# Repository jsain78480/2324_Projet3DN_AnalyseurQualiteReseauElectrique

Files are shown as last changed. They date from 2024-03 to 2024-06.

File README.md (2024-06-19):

# 2324_Projet3DN_AnalyseurQualiteReseauElectrique

# Consignes du projet
Il nous a été demandé de réaliser un projet de troisième année d'ingénieur en utilisant un STM32.
Le sujet de projet doit être validé avec le corps enseignant et doit être assez volumineux (Etaler sur 62h en autonomie).
Un GITHUB doit être créé et doit intégrer l'ensemble des éléments pour la création du projet (planning, cahier des charges, etc).
Il est préférable de réaliser un PCB 4 couches et de sous-traiter sa fabrication.
Les composants devront être soudé par les élèves. 

## Organisation du GITHUB

Nous avons ajouté différentes catégories dans notre GITHUB :
1) Hardware intègre tous les éléments permettant d'aboutir à la fabrication de nos PCB :       
   https://github.com/jsain78480/2324_Projet3DN_AnalyseurQualiteReseauElectrique/tree/main/Hardware 
2) Software intègre toute la programmation logiciel liée à STM32 Cube IDE :
   https://github.com/jsain78480/2324_Projet3DN_AnalyseurQualiteReseauElectrique/tree/main/Software
3) Projet intègre toute la méthodologie projet (Planning, cahier des charges) :
   https://github.com/jsain78480/2324_Projet3DN_AnalyseurQualiteReseauElectrique/tree/main/Projet

## Résumé du projet
Nous souhaitons réaliser un analyseur de réseau électrique dans le but d'évaluer la qualité d'un réseau electrique d'une entreprise.
Cette analyse permettra également à l'entreprise d'évaluer sa consommation électrique globale et de réévaluer l'offre qu'elle souscrit auprès de leur fournisseur.
Ce dispositif permet :
  - De récupérer la tension électrique du réseau monophasée ou triphasée
  - De mesurer le courant
  - De prélever la puissance du réseau
  - De prélever le spectre et en ressortir les harmoniques
  - D'afficher sur un écran les mesures instantannées
  - Gérer des alertes si le réseau comporte des problèmes

Le projet a commencé le 26 février et s'étend sur 62h. 
Vous pouvez trouver le planing du projet dans le répertoire projet.

## Le schéma du projet
Dessin2

## Le PCB d'acquisition



## Le PCB de traitement



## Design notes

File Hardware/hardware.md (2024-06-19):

# Carte d'acquisition permettant de récupérer le signal électrique

On a besoin d'une carte d'acquisition pour récupérer les tensions et les courants des 3 phases et du neutre de notre réseau triphasé. Pour se faire, nous allons faire un premier PCB qui sera appelé "Carte d'acquisition".
Nous avons listé ci-dessous l'ensemble des composants avec les caractéristiques techniques et les raisons du choix de ces derniers.

## Maquettage pour recherche des caractéristiques éléctriques











## Capteurs de tensions 
Référence : LEM LV 25-P 
Repères U1-U2-U3 
Rôle : Récupérer la tension de notre réseau électrique 
Composants choisis : Capteur de tension LEM LV 25-P
Raisons du choix : Le capteur LV25P est très précis et fiable, ce qui signifie qu'il mesure avec exactitude différentes tensions. Il est également facile à utiliser dans différents systèmes, ce qui le rend utile pour de nombreuses tâches. Ce dernier est donc très adapté avec notre projet d'analyseur de réseau électrique.

Caractèristiques techniques : 



Schéma technique : 



Dimensions du composants : 



Lien vers la datasheet : 

https://www.lem.com/sites/default/files/products_datasheets/lv_25-p.pdf 

Selon le datasheet "Voltage Transducer LV 25-P", on sait que :
 - Taux de conversion = 2500 : 1000
 - Courant Is = 25 mA
 - Donc conrant Iin = 10 mA

Tension d'entrée est 230 V au maximum et -230 V au minmum, donc on choisit Vin comme 500V, R1 = Vin  / Iin = 500/10mA = 50 Kohm, la puissance de l'entrée est Iin*Vin = 10*230 = 2.3 kW.

On a Vout = 3.3 V au maximum, donc Rm = Vout (au maximum) / Is = 3.3/25mA = 132 ohm.

En conclusion, le taux de la tension est : Vout/Vin = 3.3/230 = 0.0143.  

## OP1 à OP7 : AOP
Tension d'entrée : V1(Vout de U1)
Tension de sortie : V2
Resistance variable : pour calibrer V2 à 3,3V  

Tension d'entrée : Provient du traco avec +15v
Tension de sortie : 3,3v pour alimenter le STM, l'écran, les LEDS, etc

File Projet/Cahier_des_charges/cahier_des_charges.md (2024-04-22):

## Projet d'analyseur de réseau électrique 

Cadrage du besoin : 

Réaliser un analyseur de qualité de réseau électrique triphasée permettant :
- De mesurer la stabilité de la tension et du courant
- Mesures des tensions, des courants, des puissances actives, réactives et apparrentes. 
- Stabilité de la fréquence du réseau
- Mesure de la distorsion des harmoniques
- La vérification de l'équilibre des phases 

Pour informer l'utilisateur, le système doit :
- Informer l'utilisateur local avec un affichage en temps réel
- Informer un superviseur à distance avec un affichage temporel
- Pouvoir informer visuellement l'utilisateur d'une bonne ou mauvaise qualité de réseau

Enregistrement des données :
- Enregistrer en local les données mesurées
- Enregistrer à distance les données mesurées

Sécurité : 
- Le système doit garantir la sécurité de l'utilisateur

Matériels utilisés :
- Câble triphasé avec connecteur industriel 
- Coffret électrique
- Résistance de puissance pour débiter du courant
- Disjoncteur différentiel
- Pince ampéremétrique
- Carte PCB
- STM32

Spécifications techniques : 
- Tensions MAX = 230V 
- Courant MAX = 6A par phase
- Puissances Actives MAX = 
- Puissances Réactive MAX = 
- Puissances Apparentes MAX = 
- Montage souhaité = Etoile

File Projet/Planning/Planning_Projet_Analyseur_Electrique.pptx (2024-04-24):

## Planning projet analyseur électrique

Version 0 : Prévisionnel

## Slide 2

Activité

Choix du projet

Février

2024

T1

Mars

Avril

T2

Mai

Juin

Responsables

Validation du projet

Initialisation du GITHUB

26/02/2024

26/02/2024

28/02/2024

Jingwen/Hicham/Julien/Anas

Jingwen/Hicham/Julien/Anas

Mr Fiack et Mr Papazoglou

Rédaction du planning prévisionnel

Rédaction du cahier des charges

Réalisation du schéma de niveau 1 (haut niveau)

Jingwen/Hicham/Julien/Anas

Jingwen/Hicham/Julien/Anas

Jingwen/Hicham/Julien/Anas

Réalisation du schéma de niveau 3 (bas niveau)

Réalisation du schéma de niveau 2 (moyen niveau)

15/03/2024

22/03/2024

28/03/2024

Jingwen/Hicham/Julien/Anas

Jingwen/Hicham/Julien/Anas

KICAD de la carte d’acquisition

Choix des composants - Nomenclatures

KICAD de la carte de traitement

Jingwen/Hicham/Julien/Anas

Jingwen/Julien

Hicham/Anas

Débuter le software avec une carte de test (Nucléo)

Commande des composants (PCB avec GERBER)

Validation de la 1ère version des PCB

02/05/2024

17/05/2024

Jingwen/Julien

Mr Fiack et Mr Papazoglou

Mr Fiack et Mr Papazoglou

Commande des composants (hors PCB)

Réception des composants

Soudures des composants sur PCB

17/05/2024

31/05/2024

Jingwen/Hicham/Julien/Anas

Mr Fiack et Mr Papazoglou

Mr Fiack et Mr Papazoglou

Développement software phase 3 (Puissance)

Développement software phase 2 (Courants)

Développement software phase 1 (Tension)

31/05/2024

06/06/2024

07/06/2024

Jingwen/Hicham/Julien/Anas

Jingwen/Hicham/Julien/Anas

Développement software phase 4 (Harmoniques)

Développement software phase 5 (Ecran OLED)

07/06/2024

12/06/2024

Jingwen/Hicham/Julien/Anas

Jingwen/Hicham/Julien/Anas

Tests hardwares, tests softwares et validation du projet

Rédaction du planning définitif

Rédaction du retour d’expérience

Jingwen/Hicham/Julien/Anas

Jingwen/Hicham/Julien/Anas

Jingwen/Hicham/Julien/Anas

Présentation orale

Finalisation du GITHUB

14/06/2024

Jingwen/Hicham/Julien/Anas

Jingwen/Hicham/Julien/Anas

24/04/2024

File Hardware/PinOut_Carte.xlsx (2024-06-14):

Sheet: SUBD-Traitement-Acquisition
Projet Analyseur de réseau électrique
Signal | Carte d'acquisition | Cordon |  |  | Carte de traitement
Vph1 | P1-1 | P2-1 | Vph1 | P3-8 | P1-8
Vph2 | P1-2 | P2-2 | Vph2 | P3-7 | P1-7
Vph3 | P1-3 | P2-3 | Vph3 | P3-6 | P1-6
Vcurrent_ph1 | P1-9 | P2-9 | Vcurrent_ph1 | P3-15 | P1-15
Vcurrent_ph2 | P1-10 | P2-10 | Vcurrent_ph2 | P3-14 | P1-14
Vcurrent_ph3 | P1-11 | P2-11 | Vcurrent_ph3 | P3-13 | P1-13
Vcurrent_neutre | P1-4 | P2-4 | +15V | P3-5 | P1-5
+15V | P1-15 | P2-15 | Vcurrent_neutre | P3-9 | P1-9
GND | P1-8 | P2-8 | GND | P3-1 | P1-1

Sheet: SUBD-STM32
Projet Analyseur de réseau électrique
Signal | STM32G4 | Carte de traitement
Vph1 |  | P1-8
Vph2 |  | P1-7
Vph3 |  | P1-6
Vcurrent_ph1 |  | P1-15
Vcurrent_ph2 |  | P1-14
Vcurrent_ph3 |  | P1-13
Vcurrent_neutre |  | P1-5
+15V |  | P1-9
GND |  | P1-1

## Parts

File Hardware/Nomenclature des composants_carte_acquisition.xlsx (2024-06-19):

Projet Analyseur de Réseau Electrique
Nomenclature des composants
Designation | Repère CI | Références constructeur | Référence fournisseur | Quantité | Prix | Fournisseur | Prix total | Coût Carte d'acquisition | Coût carte de traitement | Coût total
 |  |  |  |  |  |  |  | 373.26 |  | 373.26
Capteur de tension | U1, U2, U3 | LV 25-P | 1617416 | 3 | 77.53 | FARNELL | 232.59
Fiches bananes 4mm femelle Rouge | J1 | SWEB 8094 AU / RT (https://fr.farnell.com/schutzinger/sweb-8094-au-rt/fiche-banane-femelle-24a-rouge/dp/3224813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) | 3224813 | 2 | 5.81 | FARNELL | 11.62
Fiches bananes 4mm femelle Jaune | J2 | SWEB 8094 AU / GE (https://fr.farnell.com/schutzinger/sweb-8094-au-ge/fiche-banane-femelle-24a-jaune/dp/3224811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) | 3224811 | 1 | 5.65 | FARNELL | 5.65
Fiches bananes 4mm femelle Bleu | J3 | SWEB 8094 AU / BL (https://fr.farnell.com/schutzinger/sweb-8094-au-bl/conn-banane-femelle-24a-bleu/dp/3224810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) | 3224810 | 1 | 5.43 | FARNELL | 5.43
Fiches bananes 4mm femelle Noir | J4 | SWEB 8094 AU / SW (https://fr.farnell.com/schutzinger/sweb-8094-au-sw/conn-banane-femelle-24a-noir/dp/3224814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) | 3224814 | 2 | 5.76 | FARNELL | 11.52
Alimentation Traco Power +/- 15V | AL1 | TMP 15215 (https://www.mouser.fr/ProductDetail/TRACO-Power/TMP-30215?qs=ckJk83FOD0XyGILCEMzHzw%3D%3D) | 495-TMP15215 | 1 | 40.39 | MOUSER | 40.39
 |  |  |  |  |  |  | 0
Connecteur SubD 15 pts Mâle | P1 | 618015231421 | 710-618015231421 | 1 | 0 | ENSEA | 0
Connecteur SubD 15 pts Femelle | P2,P3 | 61801524923 | 710-61801524923 | 2 | 2.04 | MOUSER | 4.08
Régulateur 3,3V | REG1 | LM2937ESX-3.3/NOPB | 3122059 | 1 | 2.41 | FARNELL | 2.41
Amplificateur | OP1 à OP7 | OP275GSZ (https://fr.farnell.com/analog-devices/op275gsz/ampli-op-9mhz-40-a-85-c-nsoic/dp/4021486?st=op275) | 4021486 | 7 | 4.13 | FARNELL | 28.91
Connecteur BNC | J1 à J4 |  | 217-7787 | 4 | 6.16 | RS | 24.64
Porte fusible | PF1 | MC000830 | 2461161 | 1 | 0.702 | FARNELL | 0.702
Fusible (250mA 5 x 20mm Type F 250V c.a) | F1 |  | 563-469 | 1 | 0.315 | RS | 0.315
LED verte |  |  |  | 2 | 0 | ENSEA | 0
LED Orange |  |  |  | 1 | 0 | ENSEA | 0
 |  |  |  |  |  |  | 0
Résistances 25kΩ/6W | R21, R26, R31, R36 | 356024KFT | 3231229 | 4 | 1.25 | Farnell | 5
Résistances CMS 100Ω R_0603_1608Metric_Pad0.98x0.95mm | R23, R24, R28, R29, R33, R34 |  |  |  |  |  | 0
Résistances CMS 1kΩ R_0603_1608Metric_Pad0.98x0.95mm | R3, R4, R5, R7, R8, R9, R11, R12, R13, R15, R16, R17, R19, R20, R22, R25, R27, R30, R32 |  |  | 19 | 0 | ENSEA | 0
Résistances CMS 4,5kΩ R_0603_1608Metric_Pad0.98x0.95mm | R6, R10, R14, R18 |  |  | 4 | 0 | ENSEA | 0
Résistances CMS 7,5kΩ R_0603_1608Metric_Pad0.98x0.95mm | R1, R2 |  |  | 2 | 0 | ENSEA | 0
 |  |  |  |  |  |  | 0
Condensateur CMS 0,1uF C_0603_1608Metric_Pad1.08x0.95mm | C1, C3 à C14 |  |  | 13 | 0 | ENSEA | 0
Condensateur CMS 10uF C_0603_1608Metric_Pad1.08x0.95mm | C2 |  |  | 1 | 0 | ENSEA | 0

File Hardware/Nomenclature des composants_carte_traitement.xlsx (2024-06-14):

Projet Analyseur de Réseau Electrique
Nomenclature des composants
Designation | Repère CI | Références constructeur | Référence fournisseur | Quantité | Prix | Fournisseur | Prix total | Coût carte de traitement | Coût total
 |  |  |  |  |  |  |  | 0.00 | 0.00
Microprocesseur | U2 | STM32G474RET6 | 3132418 | 1 | 0 | ENSEA | 0
MagI3C Power Module | WE1 | 173950x78 | 173950x78 | 1 | 0 | ENSEA | 0
OLED | OLED1 |  |  | 1 | 0 | ENSEA | 0
LED verte | D2 |  |  | 1 | 0 | ENSEA | 0
LED Orange | D1 |  |  | 1 | 0 | ENSEA | 0
Tact Switch | S1,S2,S3,S4 |  |  | 4 | 0 | ENSEA | 0
Connecteur SubD 15 pts Femelle | J2 | 618015231321 | 710-618015231321 | 1 | 0 | ENSEA | 0
Connecteur 02x07 Odd_Even | J1 |  |  | 1 | 0 | ENSEA | 0
Condensateur CMD 4,7uF C_0603_1608Metric_Pad1.08x0.95mm | C1 |  |  | 1 | 0 | ENSEA | 0
Condensateur CMD 100nF C_0603_1608Metric_Pad1.08x0.95mm | C2,C3,C7 |  |  | 3 | 0 | ENSEA | 0
Condensateur CMD 10nF C_0603_1608Metric_Pad1.08x0.95mm | C4,C8 à C11 |  |  | 5 | 0 | ENSEA | 0
Condensateur CMD 1uF C_0603_1608Metric_Pad1.08x0.95mm | C5,C6 |  |  | 2 | 0 | ENSEA | 0
Inductance CMD 39nH L_0603_1608Metric_Pad1.05x0.95mm | L1 |  |  | 1 | 0 | ENSEA | 0
Résistances CMS 180Ω R_0603_1608Metric_Pad0.98x0.95mm | R1 |  |  | 1 | 0 | ENSEA | 0
Résistances CMS 240Ω R_0603_1608Metric_Pad0.98x0.95mm | R2 |  |  | 1 | 0 | ENSEA | 0
Résistances CMS 10kΩ R_0603_1608Metric_Pad0.98x0.95mm | R3 à R10 |  |  | 8 | 0 | ENSEA | 0

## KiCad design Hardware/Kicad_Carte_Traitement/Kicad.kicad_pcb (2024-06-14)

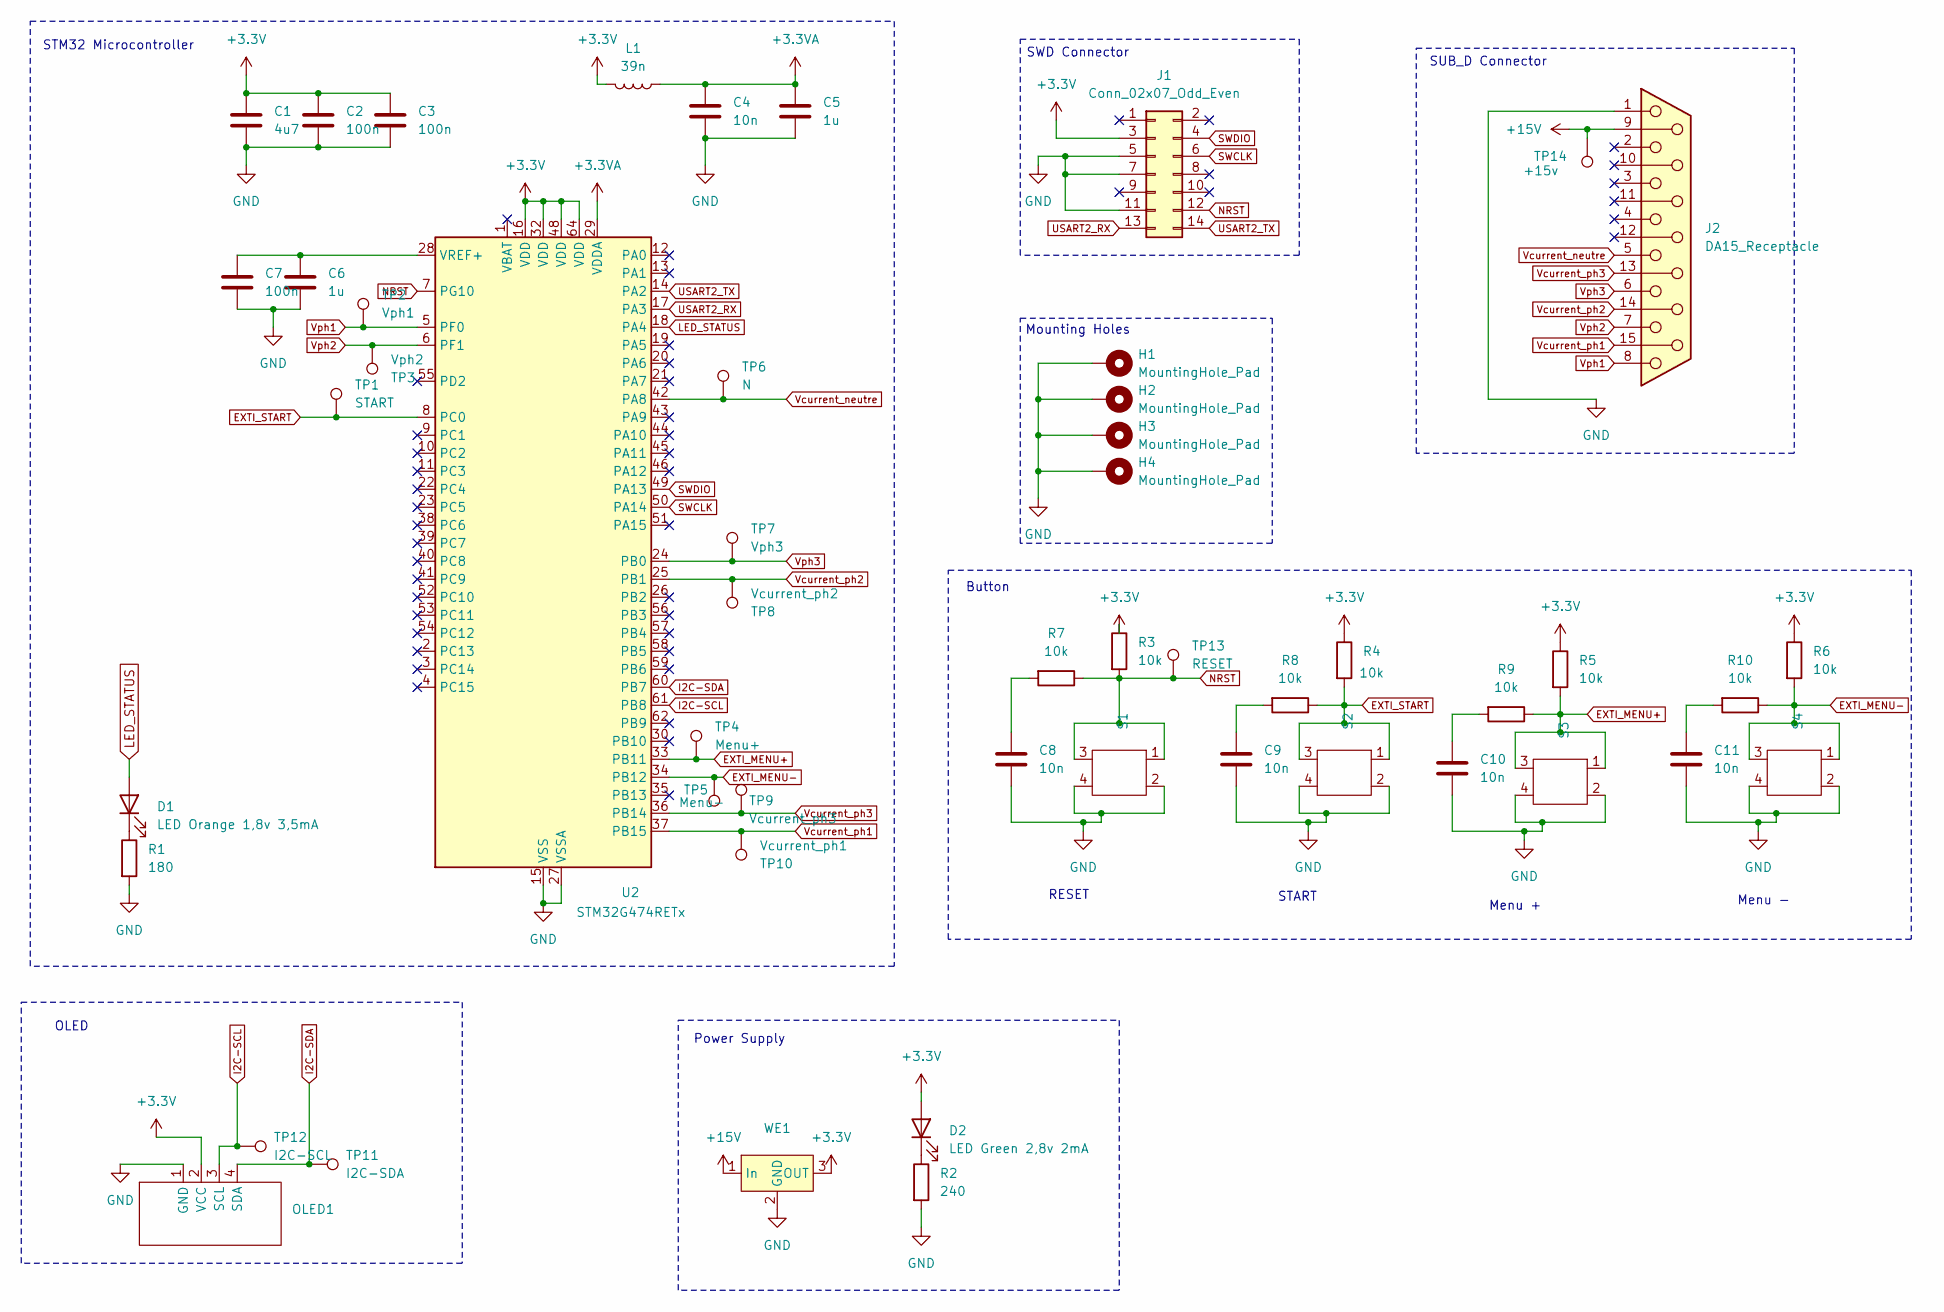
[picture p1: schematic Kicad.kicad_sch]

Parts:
C1: 4u7; C_0603_1608Metric_Pad1.08x0.95mm_HandSolder
C2, C3, C7: 100n; C_0603_1608Metric_Pad1.08x0.95mm_HandSolder
C4, C8, C9, C10, C11: 10n; C_0603_1608Metric_Pad1.08x0.95mm_HandSolder
C5, C6: 1u; C_0603_1608Metric_Pad1.08x0.95mm_HandSolder
D1: LED Orange 1,8v 3,5mA; LED_0603_1608Metric_Pad1.05x0.95mm_HandSolder
D2: LED Green 2,8v 2mA; LED_0603_1608Metric_Pad1.05x0.95mm_HandSolder
H1, H2, H3, H4: MountingHole_Pad; MountingHole_3.2mm_M3_Pad
J1: Conn_02x07_Odd_Even; IDC-Header_2x07_P2.54mm_Vertical_SMD
J2: DA15_Receptacle; 618015231321
L1: 39n; L_0603_1608Metric_Pad1.05x0.95mm_HandSolder
OLED1: OLED
R1: 180; R_0603_1608Metric_Pad0.98x0.95mm_HandSolder
R2: 240; R_0603_1608Metric_Pad0.98x0.95mm_HandSolder
R3, R4, R5, R6, R7, R8, R9, R10: 10k; R_0603_1608Metric_Pad0.98x0.95mm_HandSolder
S1, S2, S3, S4: Tact_switch
TP1: START; Pin_D1.2mm_L10.2mm_W2.9mm_FlatFork
TP2: Vph1; Pin_D1.2mm_L10.2mm_W2.9mm_FlatFork
TP3: Vph2; Pin_D1.2mm_L10.2mm_W2.9mm_FlatFork
TP4: Menu+; Pin_D1.2mm_L10.2mm_W2.9mm_FlatFork
TP5: Menu-; Pin_D1.2mm_L10.2mm_W2.9mm_FlatFork
TP6: N; Pin_D1.2mm_L10.2mm_W2.9mm_FlatFork
TP7: Vph3; Pin_D1.2mm_L10.2mm_W2.9mm_FlatFork
TP8: Vcurrent_ph2; Pin_D1.2mm_L10.2mm_W2.9mm_FlatFork
TP9: Vcurrent_ph3; Pin_D1.2mm_L10.2mm_W2.9mm_FlatFork
TP10: Vcurrent_ph1; Pin_D1.2mm_L10.2mm_W2.9mm_FlatFork
TP11: I2C-SDA; Pin_D1.2mm_L10.2mm_W2.9mm_FlatFork
TP12: I2C-SCL; Pin_D1.2mm_L10.2mm_W2.9mm_FlatFork
TP13: RESET; Pin_D1.2mm_L10.2mm_W2.9mm_FlatFork
TP14: +15v; Pin_D1.2mm_L10.2mm_W2.9mm_FlatFork
U2: STM32G474RETx; LQFP-64_10x10mm_P0.5mm
WE1: test

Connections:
+3.3V: C1.1, C2.1, C3.1, D2.2 (A), J1.3, L1.2, OLED1.2 (VCC), R3.1, R4.1, R5.1, R6.1, U2.16 (VDD), U2.32 (VDD), U2.48 (VDD), U2.64 (VDD), WE1.3 (OUT)
+3.3VA: C4.1, C5.1, L1.1, U2.29 (VDDA)
+15V: J2.9, TP14.1, WE1.1 (In)
EXTI_MENU+: R5.2, R9.1, S3.1, S3.3, TP4.1, U2.33 (PB11)
EXTI_MENU-: R6.2, R10.1, S4.1, S4.3, TP5.1, U2.34 (PB12)
EXTI_START: R4.2, R8.1, S2.1, S2.3, TP1.1, U2.8 (PC0)
GND: C1.2, C2.2, C3.2, C4.2, C5.2, C6.2, C7.2, C8.2, C9.2, C10.2, C11.2, H1.1, H2.1, H3.1, H4.1, J1.5, J1.7, J1.11, J2.1, OLED1.1 (GND), R1.2, R2.2, S1.2, S1.4, S2.2, S2.4, S3.2, S3.4, S4.2, S4.4, U2.15 (VSS), U2.27 (VSSA), U2.31 (VSS), U2.47 (VSS), U2.63 (VSS), WE1.2 (GND)
I2C-SCL: OLED1.3 (SCL), TP12.1, U2.61 (PB8)
I2C-SDA: OLED1.4 (SDA), TP11.1, U2.60 (PB7)
LED_STATUS: D1.2 (A), U2.18 (PA4)
NRST: J1.12, R3.2, R7.1, S1.1, S1.3, TP13.1, U2.7 (PG10)
unnamed: C8.1, R7.2
unnamed: C9.1, R8.2
unnamed: C10.1, R9.2
unnamed: C11.1, R10.2
unnamed: D1.1 (K), R1.1
unnamed: D2.1 (K), R2.1
unnamed: C6.1, C7.1, U2.28 (VREF+)
SWCLK: J1.6, U2.50 (PA14)
SWDIO: J1.4, U2.49 (PA13)
USART2_RX: J1.13, U2.17 (PA3)
USART2_TX: J1.14, U2.14 (PA2)
Vcurrent_neutre: J2.5, TP6.1, U2.42 (PA8)
Vcurrent_ph1: J2.15, TP10.1, U2.37 (PB15)
Vcurrent_ph2: J2.14, TP8.1, U2.25 (PB1)
Vcurrent_ph3: J2.13, TP9.1, U2.36 (PB14)
Vph1: J2.8, TP2.1, U2.5 (PF0)
Vph2: J2.7, TP3.1, U2.6 (PF1)
Vph3: J2.6, TP7.1, U2.24 (PB0)

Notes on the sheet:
STM32 Microcontroller
Power Supply
SUB_D Connector
Menu -
Button
SWD Connector
OLED
START
RESET
Menu +
Mounting Holes

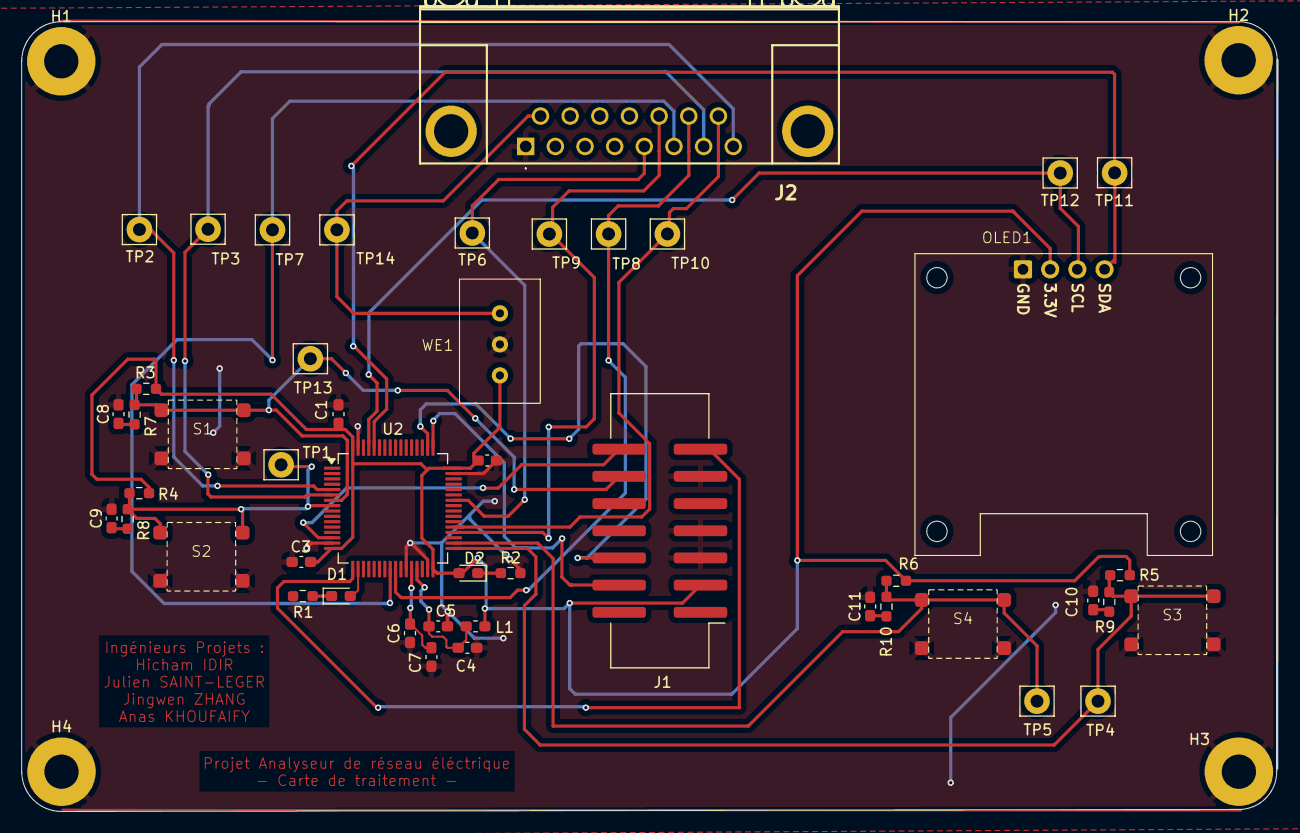
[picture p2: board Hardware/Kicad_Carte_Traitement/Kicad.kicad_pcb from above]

Board: 2 copper layers, 117.3 x 73.8 mm, 51 parts (0 on the bottom side), 29 nets.

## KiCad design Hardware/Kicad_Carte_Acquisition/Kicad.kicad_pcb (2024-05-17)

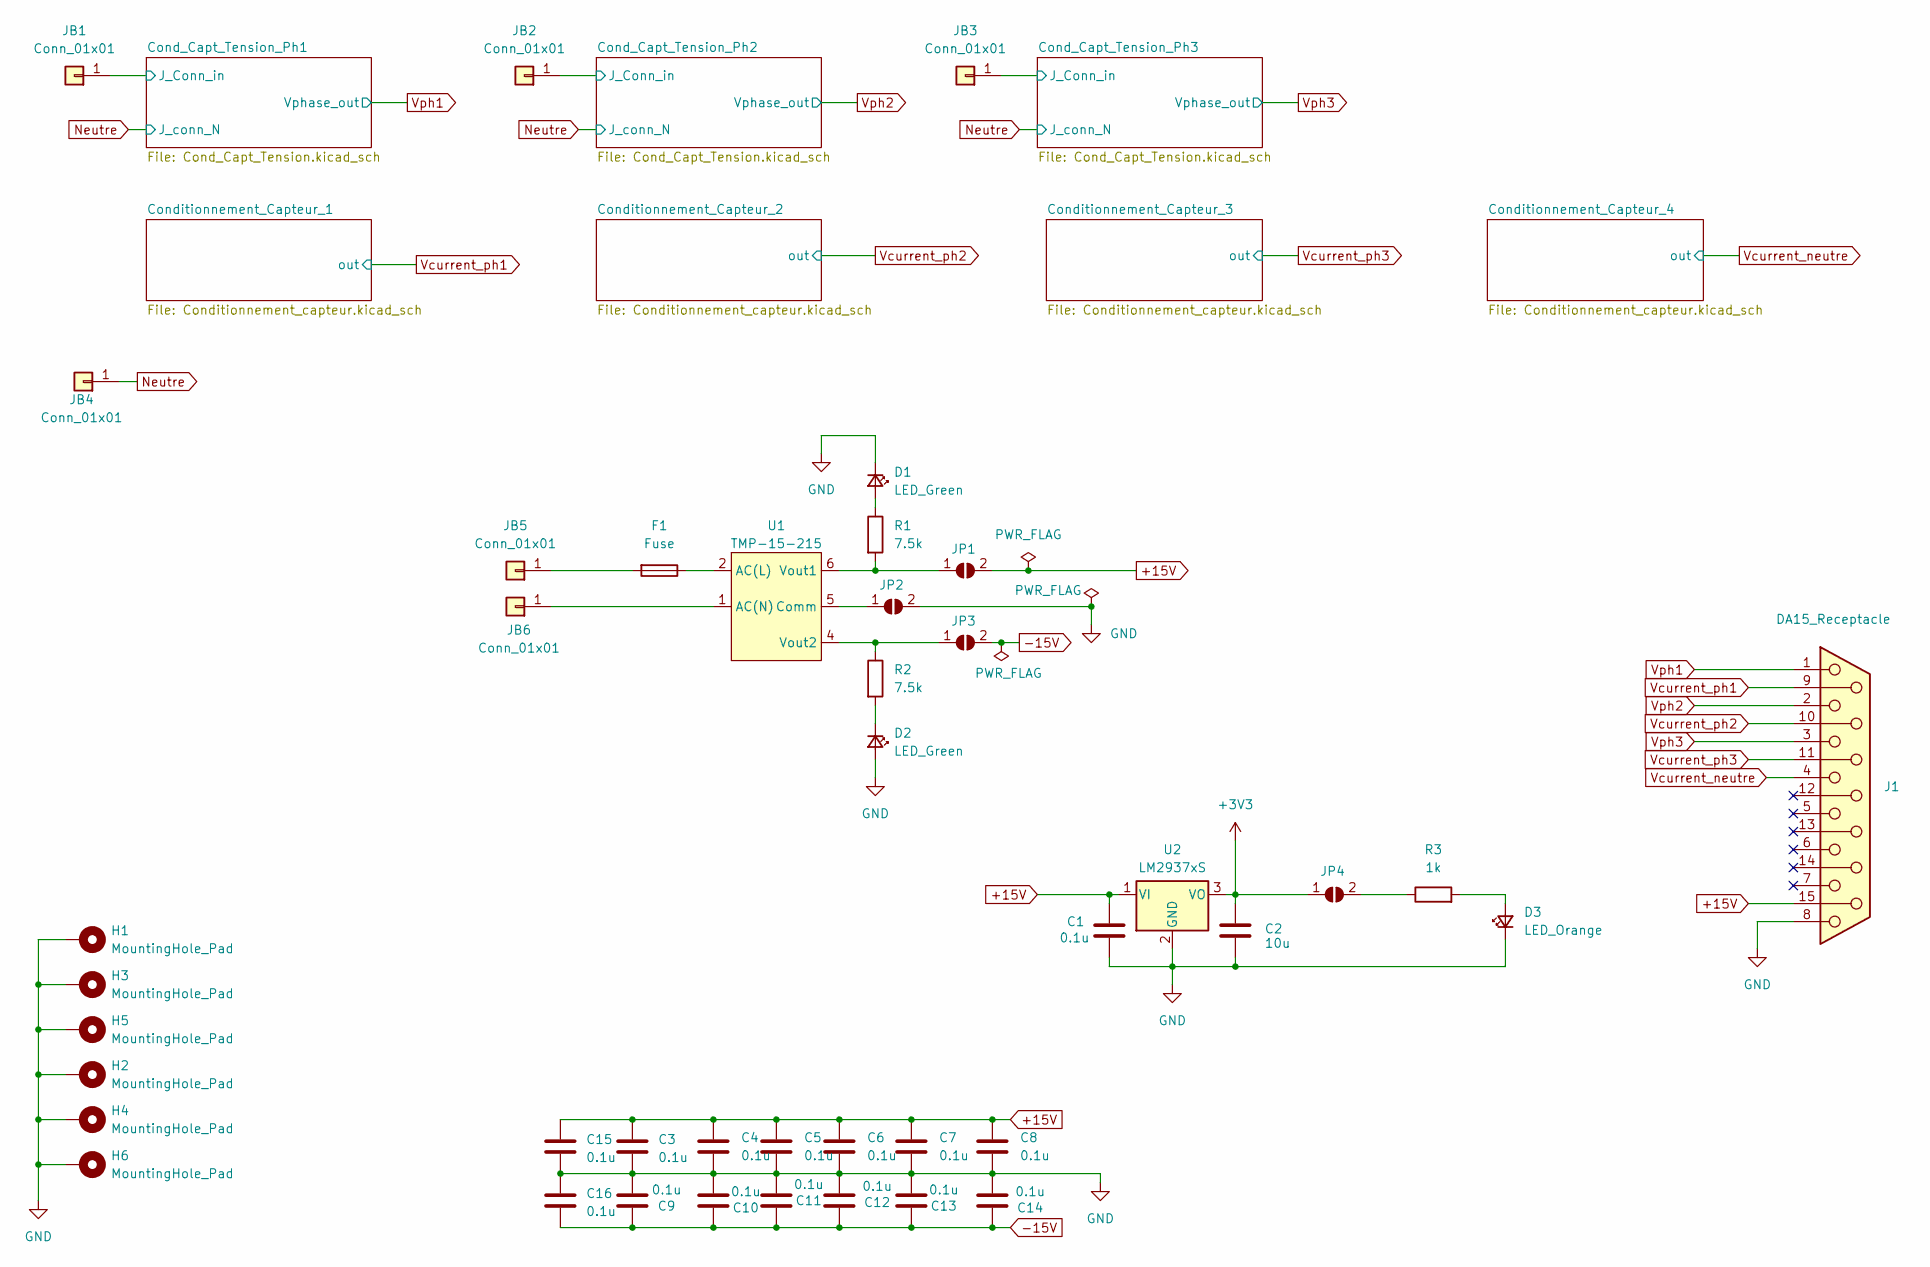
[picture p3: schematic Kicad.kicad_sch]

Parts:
C1, C3, C4, C5, C6, C7, C8, C9, C10, C11, C12, C13, C14, C15, C16: 0.1u; C_0603_1608Metric_Pad1.08x0.95mm_HandSolder
C2: 10u; C_0603_1608Metric_Pad1.08x0.95mm_HandSolder
D1, D2: LED_Green; LED_0603_1608Metric_Pad1.05x0.95mm_HandSolder
D3: LED_Orange; LED_0603_1608Metric_Pad1.05x0.95mm_HandSolder
F1: Fuse; Porte_Fusible_PC1E
H1, H2, H3, H4, H5, H6: MountingHole_Pad; MountingHole_3.2mm_M3_Pad
J1: DA15_Receptacle; 618015231321
JB1, JB2, JB3, JB4, JB5, JB6: Conn_01x01; Banana_Cliff_FCR7350B_S16N-PC_Horizontal
JP1, JP2, JP3, JP4: SolderJumper_2_Open; SolderJumper-2_P1.3mm_Open_TrianglePad1.0x1.5mm
R1, R2: 7.5k; R_0603_1608Metric_Pad0.98x0.95mm_HandSolder
R3: 1k; R_0603_1608Metric_Pad0.98x0.95mm_HandSolder
U1: TMP-15-215; TMP-15-215E
U2: LM2937xS; TO-263-3_TabPin2

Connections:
+3V3: C2.1, JP4.1 (A), U2.3 (VO); also elsewhere on the board
+15V: C1.1, C3.1, C4.1, C5.1, C6.1, C7.1, C8.1, C15.1, J1.15, JP1.2 (B), U2.1 (VI); also elsewhere on the board
-15V: C9.1, C10.1, C11.1, C12.1, C13.1, C14.1, C16.2, JP3.2 (B); also elsewhere on the board
/Cond_Capt_Tension_Ph1/J_Conn_in: JB1.1; also elsewhere on the board
/Cond_Capt_Tension_Ph2/J_Conn_in: JB2.1; also elsewhere on the board
/Cond_Capt_Tension_Ph3/J_Conn_in: JB3.1; also elsewhere on the board
GND: C1.2, C2.2, C3.2, C4.2, C5.2, C6.2, C7.2, C8.2, C9.2, C10.2, C11.2, C12.2, C13.2, C14.2, C15.2, C16.1, D1.1 (K), D2.2 (A), D3.1 (K), H1.1, H2.1, H3.1, H4.1, H5.1, H6.1, J1.8, JP2.2 (B), U2.2 (GND); also elsewhere on the board
unnamed: D1.2 (A), R1.1
unnamed: D2.1 (K), R2.2
unnamed: D3.2 (A), R3.2
unnamed: F1.2, JB5.1
unnamed: JB6.1, U1.1 (AC(N))
unnamed: JP1.1 (A), R1.2, U1.6 (Vout1)
unnamed: JP2.1 (A), U1.5 (Comm)
unnamed: JP3.1 (A), R2.1, U1.4 (Vout2)
unnamed: JP4.2 (B), R3.1
unnamed: F1.1, U1.2 (AC(L))
Neutre: JB4.1; also elsewhere on the board
Vcurrent_neutre: J1.4; also elsewhere on the board
Vcurrent_ph1: J1.9; also elsewhere on the board
Vcurrent_ph2: J1.10; also elsewhere on the board
Vcurrent_ph3: J1.11 (P111); also elsewhere on the board
Vph1: J1.1; also elsewhere on the board
Vph2: J1.2; also elsewhere on the board
Vph3: J1.3; also elsewhere on the board

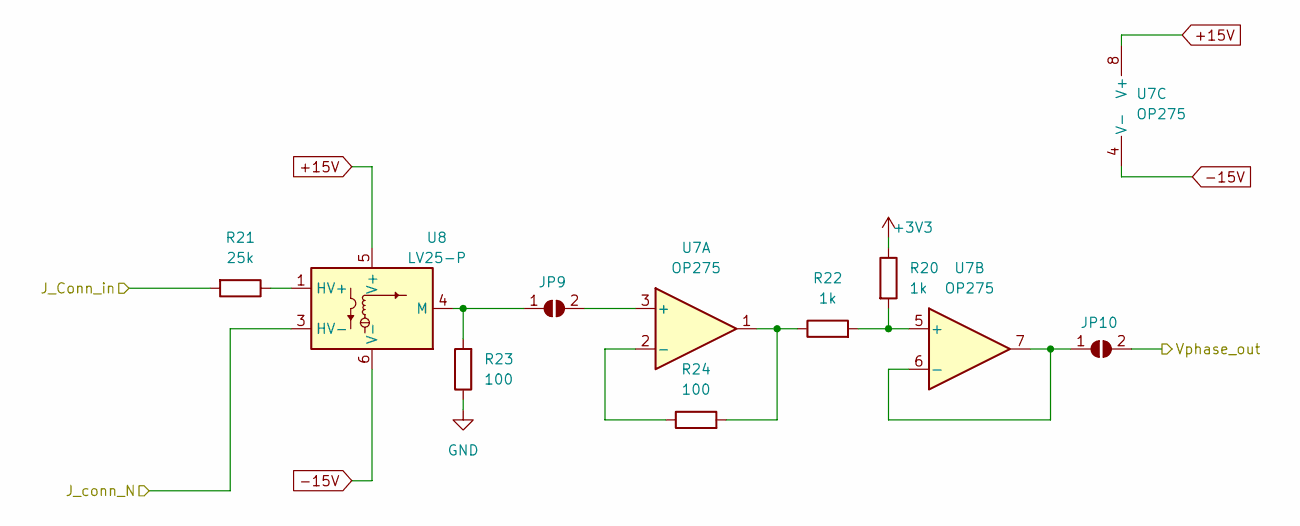
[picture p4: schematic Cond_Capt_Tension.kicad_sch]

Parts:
JP9, JP10: SolderJumper_2_Open; SolderJumper-2_P1.3mm_Open_TrianglePad1.0x1.5mm
R20, R22: 1k; R_0603_1608Metric_Pad0.98x0.95mm_HandSolder
R21: 25k; R_4527_M11470E
R23, R24: 100; R_0603_1608Metric_Pad0.98x0.95mm_HandSolder
U7: OP275; SOIC-8_3.9x4.9mm_P1.27mm
U8: LV25-P; LEM_LV25-P

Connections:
+3V3: R20.1; also elsewhere on the board
+15V: U7.8 (V+), U8.5 (V+); also elsewhere on the board
-15V: U7.4 (V-), U8.6 (V-); also elsewhere on the board
/Cond_Capt_Tension_Ph1/J_Conn_in: R21.2; also elsewhere on the board
GND: R23.1; also elsewhere on the board
unnamed: JP9.1 (A), R23.2, U8.4 (M)
unnamed: JP9.2 (B), U7.3 (+)
unnamed: JP10.1 (A), U7.6 (-), U7.7
unnamed: R22.1, R24.2, U7.1
unnamed: R24.1, U7.2 (-)
unnamed: R20.2, R22.2, U7.5 (+)
unnamed: R21.1, U8.1 (HV+)
Neutre: U8.3 (HV-); also elsewhere on the board
Vph1: JP10.2 (B); also elsewhere on the board

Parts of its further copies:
JP11, JP12, JP13, JP14: SolderJumper_2_Open; SolderJumper-2_P1.3mm_Open_TrianglePad1.0x1.5mm
R25, R27, R30, R32: 1k; R_0603_1608Metric_Pad0.98x0.95mm_HandSolder
R26, R31: 25k; R_4527_M11470E
R28, R29, R33, R34: 100; R_0603_1608Metric_Pad0.98x0.95mm_HandSolder
U9, U11: OP275; SOIC-8_3.9x4.9mm_P1.27mm
U10, U12: LV25-P; LEM_LV25-P

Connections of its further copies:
+3V3: R25.1, R30.1; also elsewhere on the board
+15V: U9.8 (V+), U10.5 (V+), U11.8 (V+), U12.5 (V+); also elsewhere on the board
-15V: U9.4 (V-), U10.6 (V-), U11.4 (V-), U12.6 (V-); also elsewhere on the board
/Cond_Capt_Tension_Ph2/J_Conn_in: R26.2; also elsewhere on the board
/Cond_Capt_Tension_Ph3/J_Conn_in: R31.2; also elsewhere on the board
GND: R28.1, R33.1; also elsewhere on the board
unnamed: JP11.1 (A), R28.2, U10.4 (M)
unnamed: JP11.2 (B), U9.3 (+)
unnamed: JP12.1 (A), U9.6 (-), U9.7
unnamed: JP13.1 (A), R33.2, U12.4 (M)
unnamed: JP13.2 (B), U11.3 (+)
unnamed: JP14.1 (A), U11.6 (-), U11.7
unnamed: R27.1, R29.2, U9.1
unnamed: R32.1, R34.2, U11.1
unnamed: R29.1, U9.2 (-)
unnamed: R25.2, R27.2, U9.5 (+)
unnamed: R26.1, U10.1 (HV+)
unnamed: R34.1, U11.2 (-)
unnamed: R30.2, R32.2, U11.5 (+)
unnamed: R31.1, U12.1 (HV+)
Neutre: U10.3 (HV-), U12.3 (HV-); also elsewhere on the board
Vph2: JP12.2 (B); also elsewhere on the board
Vph3: JP14.2 (B); also elsewhere on the board

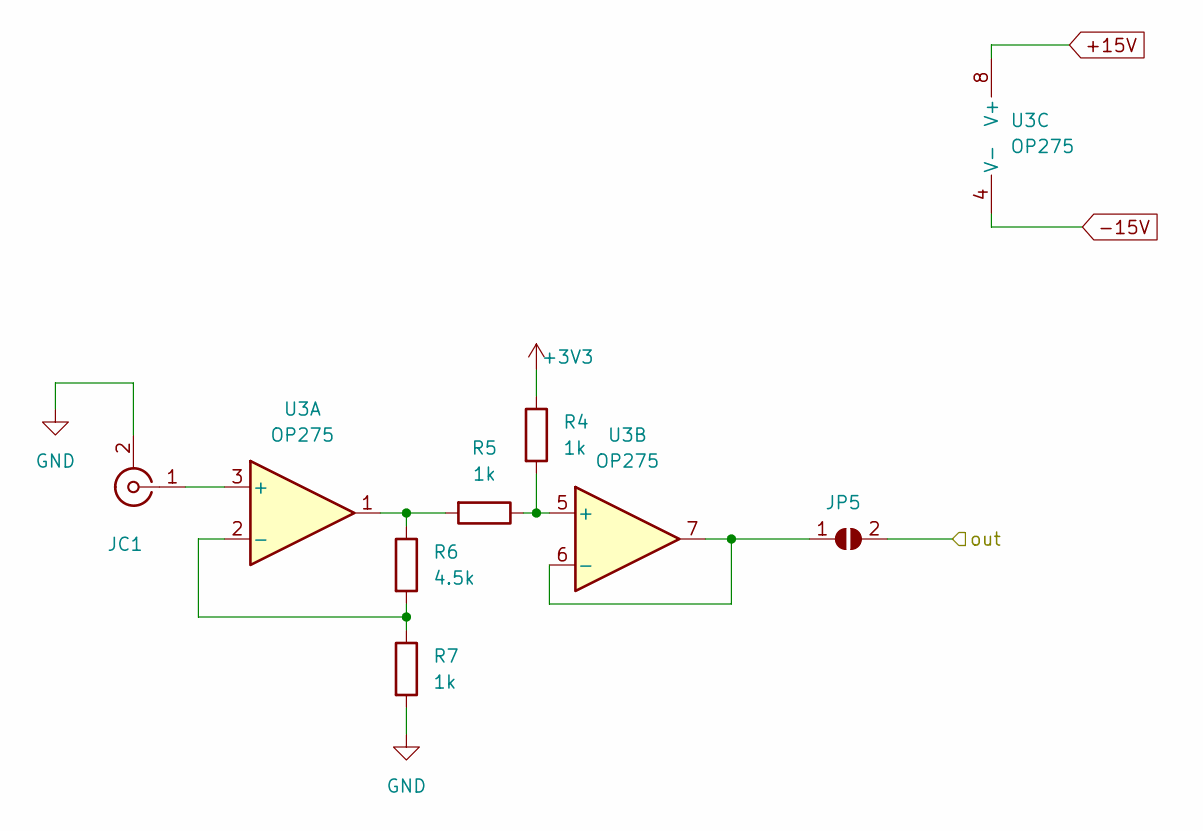
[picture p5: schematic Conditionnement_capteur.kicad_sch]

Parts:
JC1: Conn_Coaxial; Conn_CoaxE
JP5: SolderJumper_2_Open; SolderJumper-2_P1.3mm_Open_TrianglePad1.0x1.5mm
R4, R5, R7: 1k; R_0603_1608Metric_Pad0.98x0.95mm_HandSolder
R6: 4.5k; R_0603_1608Metric_Pad0.98x0.95mm_HandSolder
U3: OP275; SOIC-8_3.9x4.9mm_P1.27mm

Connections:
+3V3: R4.1; also elsewhere on the board
+15V: U3.8 (V+); also elsewhere on the board
-15V: U3.4 (V-); also elsewhere on the board
GND: JC1.2 (Ext), R7.2; also elsewhere on the board
unnamed: JC1.1 (In), U3.3 (+)
unnamed: JP5.1 (A), U3.6 (-), U3.7
unnamed: R5.2, R6.1, U3.1
unnamed: R6.2, R7.1, U3.2 (-)
unnamed: R4.2, R5.1, U3.5 (+)
Vcurrent_ph1: JP5.2 (B); also elsewhere on the board

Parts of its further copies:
JC2, JC3, JC4: Conn_Coaxial; Conn_CoaxE
JP6, JP7, JP8: SolderJumper_2_Open; SolderJumper-2_P1.3mm_Open_TrianglePad1.0x1.5mm
R8, R9, R11, R12, R13, R15, R16, R17, R19: 1k; R_0603_1608Metric_Pad0.98x0.95mm_HandSolder
R10, R14, R18: 4.5k; R_0603_1608Metric_Pad0.98x0.95mm_HandSolder
U4, U5, U6: OP275; SOIC-8_3.9x4.9mm_P1.27mm

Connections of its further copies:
+3V3: R8.1, R12.1, R16.1; also elsewhere on the board
+15V: U4.8 (V+), U5.8 (V+), U6.8 (V+); also elsewhere on the board
-15V: U4.4 (V-), U5.4 (V-), U6.4 (V-); also elsewhere on the board
GND: JC2.2 (Ext), JC3.2 (Ext), JC4.2 (Ext), R11.2, R15.2, R19.2; also elsewhere on the board
unnamed: JC2.1 (In), U4.3 (+)
unnamed: JC3.1 (In), U5.3 (+)
unnamed: JC4.1 (In), U6.3 (+)
unnamed: JP6.1 (A), U4.6 (-), U4.7
unnamed: JP7.1 (A), U5.6 (-), U5.7
unnamed: JP8.1 (A), U6.6 (-), U6.7
unnamed: R9.2, R10.1, U4.1
unnamed: R13.2, R14.1, U5.1
unnamed: R17.2, R18.1, U6.1
unnamed: R10.2, R11.1, U4.2 (-)
unnamed: R8.2, R9.1, U4.5 (+)
unnamed: R14.2, R15.1, U5.2 (-)
unnamed: R12.2, R13.1, U5.5 (+)
unnamed: R18.2, R19.1, U6.2 (-)
unnamed: R16.2, R17.1, U6.5 (+)
Vcurrent_neutre: JP8.2 (B); also elsewhere on the board
Vcurrent_ph2: JP6.2 (B); also elsewhere on the board
Vcurrent_ph3: JP7.2 (B); also elsewhere on the board

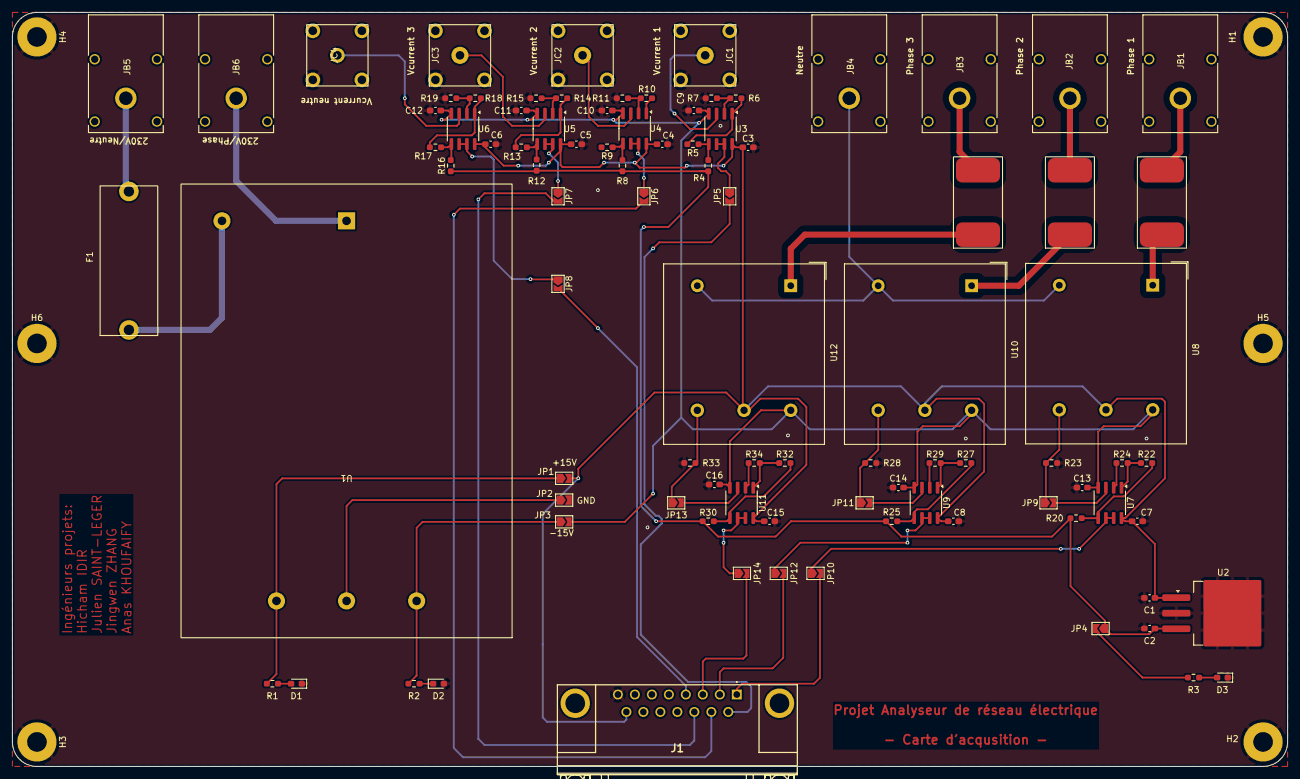
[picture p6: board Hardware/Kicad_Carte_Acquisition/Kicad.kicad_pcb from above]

Board: 2 copper layers, 208.0 x 123.0 mm, 97 parts (0 on the bottom side), 66 nets.

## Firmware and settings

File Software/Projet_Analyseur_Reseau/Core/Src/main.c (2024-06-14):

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
/* Includes ------------------------------------------------------------------*/
#include "main.h"
#include "adc.h"
#include "dma.h"
#include "i2c.h"
#include "tim.h"
#include "usart.h"
#include "gpio.h"

/* USER CODE BEGIN Includes */
#include "stm32f7xx_hal.h"
#include <stdio.h>
#include <string.h>
#include "oled.h"

/* USER CODE END Includes */


/* USER CODE BEGIN PV */
#define ADC_BUFFER_LENGTH 1024 // Taille du buffer
uint16_t adcBuffer[ADC_BUFFER_LENGTH]; // Déclaration du buffer pour les valeurs ADC
/* USER CODE END PV */

void SystemClock_Config(void);
/* USER CODE BEGIN 0 */

int __io_putchar(int chr)
{
	HAL_UART_Transmit(&huart1,(uint8_t *)&chr,1,HAL_MAX_DELAY);
	return chr;
}

// Déclaration des handles utilisés
//extern ADC_HandleTypeDef hadc3;
//extern UART_HandleTypeDef huart1;
//extern TIM_HandleTypeDef htim8;

uint16_t adcValue;
uint8_t adc_available = 0;
uint32_t test = 0;

// Buffer pour stocker la chaîne de caractères à envoyer via l'UART
char uartBuffer[50];

void HAL_ADC_ConvCpltCallback(ADC_HandleTypeDef* hadc)
{
	if (ADC3 == hadc->Instance)
	{
		adcValue = HAL_ADC_GetValue(&hadc3) ;
		test++;
		adc_available = 1;
	}
}
/* USER CODE END 0 */

/**
  * @brief  The application entry point.
  * @retval int
  */
int main(void)
{
  /* MCU Configuration--------------------------------------------------------*/

  /* Reset of all peripherals, Initializes the Flash interface and the Systick. */
  HAL_Init();

  /* USER CODE BEGIN Init */
	SystemClock_Config();
	MX_GPIO_Init();
	MX_ADC3_Init();
	MX_USART1_UART_Init();
	MX_TIM8_Init();

	HAL_ADC_Start_DMA(&hadc3, (uint32_t*)adcBuffer, ADC_BUFFER_LENGTH);

  /* USER CODE END Init */

  /* Configure the system clock */
  SystemClock_Config();

  /* Initialize all configured peripherals */
  MX_GPIO_Init();
  MX_DMA_Init();
  MX_TIM8_Init();
  MX_USART1_UART_Init();
  MX_ADC3_Init();
  MX_I2C1_Init();

  /* USER CODE BEGIN 2 */


	HAL_ADC_Start_IT(&hadc3);
	HAL_TIM_Base_Start(&htim8);

	printf("\r\n===============================================\r\n");
	uint32_t before, after;
	before = test;
	HAL_Delay(1000);
	after = test;
	uint32_t test_old;

	printf("%d %d\r\n", before, after);

	//Pour SSD1306
	tx_Buffer_Size = snprintf((char *)uart1_Tx_Buffer, UART_TX_BUFFER_SIZE, "Simple code for SSD1306 OLED Screen\r\n");

	HAL_UART_Transmit(&huart1, uart1_Tx_Buffer, tx_Buffer_Size, 10);
		if(HAL_OK == SCREEN_SSD1306_Init(&hscreen1, &hi2c1)){
			tx_Buffer_Size = snprintf((char *)uart1_Tx_Buffer, UART_TX_BUFFER_SIZE, "Screen Init Done\r\n");
			HAL_UART_Transmit(&huart1, uart1_Tx_Buffer, tx_Buffer_Size, 10);
		}
		else{
			tx_Buffer_Size = snprintf((char *)uart1_Tx_Buffer, UART_TX_BUFFER_SIZE, "Screen Init Error\r\n");
			HAL_UART_Transmit(&huart1, uart1_Tx_Buffer, tx_Buffer_Size, 10);
		}
		int dir = 1;
		while(1){
			SSD1306_COLOR color = Black;
			SCREEN_SSD1306_Fill(&hscreen1, color);
			color = White;
			SCREEN_SSD1306_Write_String(&hscreen1, "Hello ENSEA", Font_11x18, color);
			hscreen1.CurrentX = 0;
			hscreen1.CurrentY += dir;
			if(hscreen1.CurrentY == 45) dir = -1;
			if(hscreen1.CurrentY == 0) dir = 1;
			HAL_GPIO_WritePin(OSC_TRIG_GPIO_Port, OSC_TRIG_Pin, SET);
			SCREEN_SSD1306_Update_Screen(&hscreen1);
			HAL_GPIO_WritePin(OSC_TRIG_GPIO_Port, OSC_TRIG_Pin, RESET);
			HAL_Delay(20);
		}

  /* USER CODE END 2 */

  /* Infinite loop */
  /* USER CODE BEGIN WHILE */
	while (1)
	{
		if (1 == adc_available)
		{
			adc_available = 0;

			// 0V -> 0 ; 3V3 => 4095 (2^12-1)
			printf("ADC value = %d = %f (%d:%d)\r\n", adcValue, (float)(adcValue) * 3.3 / 4095.0, test, test-test_old);
			test_old = test;

			HAL_Delay(1000);
		}

    /* USER CODE END WHILE */

    /* USER CODE BEGIN 3 */
	}
  /* USER CODE END 3 */
}

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
/**
  * @brief  Period elapsed callback in non blocking mode
  * @note   This function is called  when TIM6 interrupt took place, inside
  * HAL_TIM_IRQHandler(). It makes a direct call to HAL_IncTick() to increment
  * a global variable "uwTick" used as application time base.
  * @param  htim : TIM handle
  * @retval None
  */
void HAL_TIM_PeriodElapsedCallback(TIM_HandleTypeDef *htim)
{
  if (htim->Instance == TIM6) {
    HAL_IncTick();
  }
}

/**
  * @brief  This function is executed in case of error occurrence.
  * @retval None
  */
void Error_Handler(void)
{
  /* USER CODE BEGIN Error_Handler_Debug */
	/* User can add his own implementation to report the HAL error return state */
	__disable_irq();
	while (1)
	{
	}
  /* USER CODE END Error_Handler_Debug */
}

#ifdef  USE_FULL_ASSERT
/**
  * @brief  Reports the name of the source file and the source line number
  *         where the assert_param error has occurred.
  * @param  file: pointer to the source file name
  * @param  line: assert_param error line source number
  * @retval None
  */
void assert_failed(uint8_t *file, uint32_t line)
{
  /* USER CODE BEGIN 6 */
	/* User can add his own implementation to report the file name and line number,
     ex: printf("Wrong parameters value: file %s on line %d\r\n", file, line) */
  /* USER CODE END 6 */
}
#endif /* USE_FULL_ASSERT */

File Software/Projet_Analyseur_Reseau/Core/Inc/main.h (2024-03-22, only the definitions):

#define LCD_B0_Pin GPIO_PIN_4
#define LCD_B0_GPIO_Port GPIOE
#define OTG_HS_OverCurrent_Pin GPIO_PIN_3
#define OTG_HS_OverCurrent_GPIO_Port GPIOE
#define QSPI_D2_Pin GPIO_PIN_2
#define QSPI_D2_GPIO_Port GPIOE
#define RMII_TXD1_Pin GPIO_PIN_14
#define RMII_TXD1_GPIO_Port GPIOG
#define FMC_NBL1_Pin GPIO_PIN_1
#define FMC_NBL1_GPIO_Port GPIOE
#define FMC_NBL0_Pin GPIO_PIN_0
#define FMC_NBL0_GPIO_Port GPIOE
#define ARDUINO_SCL_D15_Pin GPIO_PIN_8
#define ARDUINO_SCL_D15_GPIO_Port GPIOB
#define ULPI_D7_Pin GPIO_PIN_5
#define ULPI_D7_GPIO_Port GPIOB
#define ARDUINO_PWM_D3_Pin GPIO_PIN_4
#define ARDUINO_PWM_D3_GPIO_Port GPIOB
#define SWO_Pin GPIO_PIN_3
#define SWO_GPIO_Port GPIOB
#define SPDIF_RX0_Pin GPIO_PIN_7
#define SPDIF_RX0_GPIO_Port GPIOD
#define SDMMC_CK_Pin GPIO_PIN_12
#define SDMMC_CK_GPIO_Port GPIOC
#define ARDUINO_PWM_D9_Pin GPIO_PIN_15
#define ARDUINO_PWM_D9_GPIO_Port GPIOA
#define SWCLK_Pin GPIO_PIN_14
#define SWCLK_GPIO_Port GPIOA
#define SWDIO_Pin GPIO_PIN_13
#define SWDIO_GPIO_Port GPIOA
#define DCMI_D6_Pin GPIO_PIN_5
#define DCMI_D6_GPIO_Port GPIOE
#define DCMI_D7_Pin GPIO_PIN_6
#define DCMI_D7_GPIO_Port GPIOE
#define RMII_TXD0_Pin GPIO_PIN_13
#define RMII_TXD0_GPIO_Port GPIOG
#define ARDUINO_SDA_D14_Pin GPIO_PIN_9
#define ARDUINO_SDA_D14_GPIO_Port GPIOB
#define VCP_RX_Pin GPIO_PIN_7
#define VCP_RX_GPIO_Port GPIOB
#define QSPI_NCS_Pin GPIO_PIN_6
#define QSPI_NCS_GPIO_Port GPIOB
#define FMC_SDNCAS_Pin GPIO_PIN_15
#define FMC_SDNCAS_GPIO_Port GPIOG
#define RMII_TX_EN_Pin GPIO_PIN_11
#define RMII_TX_EN_GPIO_Port GPIOG
#define LCD_B1_Pin GPIO_PIN_13
#define LCD_B1_GPIO_Port GPIOJ
#define OTG_FS_VBUS_Pin GPIO_PIN_12
#define OTG_FS_VBUS_GPIO_Port GPIOJ
#define Audio_INT_Pin GPIO_PIN_6
#define Audio_INT_GPIO_Port GPIOD
#define FMC_D2_Pin GPIO_PIN_0
#define FMC_D2_GPIO_Port GPIOD
#define SDMMC_D3_Pin GPIO_PIN_11
#define SDMMC_D3_GPIO_Port GPIOC
#define SDMMC_D2_Pin GPIO_PIN_10
#define SDMMC_D2_GPIO_Port GPIOC
#define OTG_FS_P_Pin GPIO_PIN_12
#define OTG_FS_P_GPIO_Port GPIOA
#define NC1_Pin GPIO_PIN_8
#define NC1_GPIO_Port GPIOI
#define SAI2_MCLKA_Pin GPIO_PIN_4
#define SAI2_MCLKA_GPIO_Port GPIOI
#define LCD_DE_Pin GPIO_PIN_7
#define LCD_DE_GPIO_Port GPIOK
#define LCD_B7_Pin GPIO_PIN_6
#define LCD_B7_GPIO_Port GPIOK
#define LCD_B6_Pin GPIO_PIN_5
#define LCD_B6_GPIO_Port GPIOK
#define LCD_B4_Pin GPIO_PIN_12
#define LCD_B4_GPIO_Port GPIOG
#define SAI2_SDB_Pin GPIO_PIN_10
#define SAI2_SDB_GPIO_Port GPIOG
#define LCD_B2_Pin GPIO_PIN_14
#define LCD_B2_GPIO_Port GPIOJ
#define OTG_FS_PowerSwitchOn_Pin GPIO_PIN_5
#define OTG_FS_PowerSwitchOn_GPIO_Port GPIOD
#define DCMI_D5_Pin GPIO_PIN_3
#define DCMI_D5_GPIO_Port GPIOD
#define FMC_D3_Pin GPIO_PIN_1
#define FMC_D3_GPIO_Port GPIOD
#define ARDUINO_D7_Pin GPIO_PIN_3
#define ARDUINO_D7_GPIO_Port GPIOI
#define ARDUINO_D8_Pin GPIO_PIN_2
#define ARDUINO_D8_GPIO_Port GPIOI
#define OTG_FS_N_Pin GPIO_PIN_11
#define OTG_FS_N_GPIO_Port GPIOA
#define uSD_Detect_Pin GPIO_PIN_13
#define uSD_Detect_GPIO_Port GPIOC
#define FMC_A0_Pin GPIO_PIN_0
#define FMC_A0_GPIO_Port GPIOF
#define SAI2_SCKA_Pin GPIO_PIN_5
#define SAI2_SCKA_GPIO_Port GPIOI
#define SAI2_FSA_Pin GPIO_PIN_7
#define SAI2_FSA_GPIO_Port GPIOI
#define LCD_HSYNC_Pin GPIO_PIN_10
#define LCD_HSYNC_GPIO_Port GPIOI
#define SAI2_SDA_Pin GPIO_PIN_6
#define SAI2_SDA_GPIO_Port GPIOI
#define LCD_B5_Pin GPIO_PIN_4
#define LCD_B5_GPIO_Port GPIOK
#define LCD_BL_CTRL_Pin GPIO_PIN_3
#define LCD_BL_CTRL_GPIO_Port GPIOK
#define DCMI_VSYNC_Pin GPIO_PIN_9
#define DCMI_VSYNC_GPIO_Port GPIOG
#define LCD_B3_Pin GPIO_PIN_15
#define LCD_B3_GPIO_Port GPIOJ
#define OTG_FS_OverCurrent_Pin GPIO_PIN_4
#define OTG_FS_OverCurrent_GPIO_Port GPIOD
#define SDMMC_D0_Pin GPIO_PIN_2
#define SDMMC_D0_GPIO_Port GPIOD
#define TP3_Pin GPIO_PIN_15
#define TP3_GPIO_Port GPIOH
#define ARDUINO_SCK_D13_Pin GPIO_PIN_1
#define ARDUINO_SCK_D13_GPIO_Port GPIOI
#define OTG_FS_ID_Pin GPIO_PIN_10
#define OTG_FS_ID_GPIO_Port GPIOA
#define RCC_OSC32_IN_Pin GPIO_PIN_14
#define RCC_OSC32_IN_GPIO_Port GPIOC
#define FMC_A1_Pin GPIO_PIN_1
#define FMC_A1_GPIO_Port GPIOF
#define LCD_DISP_Pin GPIO_PIN_12
#define LCD_DISP_GPIO_Port GPIOI
#define LCD_VSYNC_Pin GPIO_PIN_9
#define LCD_VSYNC_GPIO_Port GPIOI
#define DCMI_PWR_EN_Pin GPIO_PIN_13
#define DCMI_PWR_EN_GPIO_Port GPIOH
#define DCMI_D4_Pin GPIO_PIN_14
#define DCMI_D4_GPIO_Port GPIOH
#define ARDUINO_PWM_CS_D5_Pin GPIO_PIN_0
#define ARDUINO_PWM_CS_D5_GPIO_Port GPIOI
#define VCP_TX_Pin GPIO_PIN_9
#define VCP_TX_GPIO_Port GPIOA
#define RCC_OSC32_OUT_Pin GPIO_PIN_15
#define RCC_OSC32_OUT_GPIO_Port GPIOC
#define LCD_G6_Pin GPIO_PIN_1
#define LCD_G6_GPIO_Port GPIOK
#define LCD_G7_Pin GPIO_PIN_2
#define LCD_G7_GPIO_Port GPIOK
#define ARDUINO_PWM_D10_Pin GPIO_PIN_8
#define ARDUINO_PWM_D10_GPIO_Port GPIOA
#define OSC_25M_Pin GPIO_PIN_0
#define OSC_25M_GPIO_Port GPIOH
#define FMC_A2_Pin GPIO_PIN_2
#define FMC_A2_GPIO_Port GPIOF
#define LCD_INT_Pin GPIO_PIN_13
#define LCD_INT_GPIO_Port GPIOI
#define LCD_R0_Pin GPIO_PIN_15
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

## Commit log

2024-02-26 Ajout KICAD
    [Kicad.kicad_pcb, Kicad.kicad_sch]
2024-03-15 capteur de la tension
2024-04-04 Récupération tension avec ADC - sans tableau
2024-04-22 Update Nomenclature des composants.xlsx
    [Nomenclature des composants.xlsx]
2024-05-05 maj ju
    [Kicad.kicad_pcb, Kicad.kicad_sch]

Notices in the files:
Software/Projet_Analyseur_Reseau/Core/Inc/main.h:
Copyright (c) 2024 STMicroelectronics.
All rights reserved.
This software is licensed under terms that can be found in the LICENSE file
